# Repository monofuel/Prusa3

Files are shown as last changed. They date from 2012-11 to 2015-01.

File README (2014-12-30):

Modified by monofuel
for monofuel's prusa i3

changes made for 3mm filament and 3/8ths coupling

This is Prusa iteration 3
Published under GPL v3

To start:
Copy configuration.scad.dist to configuration.scad and fill custom
settings section there

RP every .scad in this directory (except complete-printer) once.
Aim for 0.3mm layers and 2.2 extrusion width (width over thickness),
for 0.66mm stroke width. Printer is tested at this setting.

Using doc/complete-printer.scad as a visual clue and doc/manual.txt as a
guide, build the printer.

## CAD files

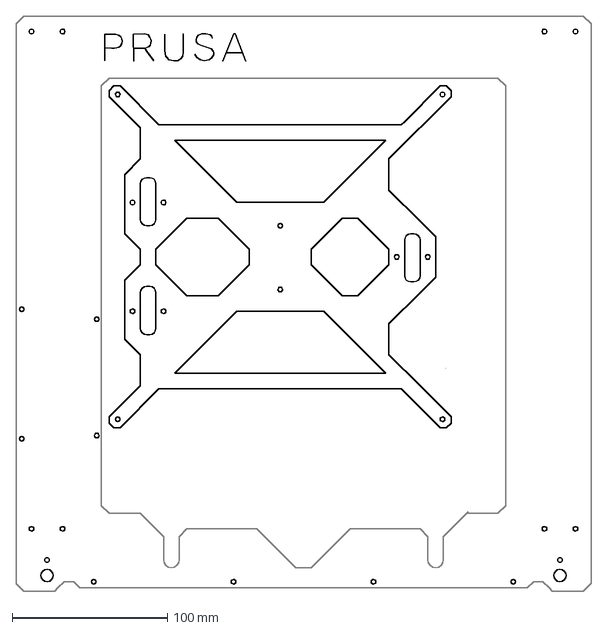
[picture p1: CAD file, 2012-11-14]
src/framev3.dxf
370.0 x 370.0 mm

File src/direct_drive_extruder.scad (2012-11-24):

/*
Designed by indieflow <indieflow@gmail.com>
Direct drive extruder for use with a nema 17 stepper motor and makerbot mk7 drive gear. 
The extruder is designed to use a bowden cable system for 1.75mm filament.
Can be mounted directly on the frame of the new Prusa i3.
The face of the extruder is left open for easy cleaning of the drive gear.
Ajustment of the idler spring tension is achieved by tightening the 4x long m3 screws which are positioned along with the springs and washers at the front of the extruder.
625 bearing on the top of the extruder is for stepper shaft support (not a requirement if no bearings available).
*/

/*
requires:
4x m3 nuts.
8x m3 washers
5x m3x10mm cap screws.
2x m3x14mm cap screws.
4x m3x40mm cap screws.
1x 4mmx12mm round bar or threaded bar. 	//Cut a m4 bolt to size.
1x 4mm OD, 2mm ID pneumatic fitting with m5 thread.
1x mk7 drive gear.
1x 624 bearing.							//idler bearing.
1x 625 bearing.							//used for motor shaft support, can be used without.
4x springs.

Jobs to do:
Assess the fit of the bearing in the idler and main block.
*/

//globals
clearance 	= 0.2;			//adjust if tight or slack once printed.
layer_height	= 0.3;			//used for removable structure.

//uncomment to view.
assembled();				//shows components assembled in position.
//printable();					//places parts in position for exporting as a printable stl.



module printable(){
translate([6,-12,10]) rotate([-90,0,0]) extruder();
translate([26.5,0,0]) rotate([0,0,0]) idler();
translate([20,23,0]) rotate([0,-90,0]) extruder_holder();
//motor bridge supports
translate([0,0,7.25]) cube(([18,2,14.5]),center=true);
translate([0,0,(layer_height/2)+2.2]) cube(([18,25,layer_height]),center=true);
translate([0,0,(layer_height/2)+14.5]) cube(([18,14,layer_height]),center=true);
//idler fixing blanks
translate([35.5,4,2.15]) cylinder(r=2,h=layer_height,center=true,$fn=20);
translate([35.5,-4,2.15]) cylinder(r=2,h=layer_height,center=true,$fn=20);
translate([17.5,-4,2.15]) cylinder(r=2,h=layer_height,center=true,$fn=20);
translate([17.5,4,2.15]) cylinder(r=2,h=layer_height,center=true,$fn=20);
}

module assembled(){
translate([6,-12,57]) rotate([-90,0,0]){
extruder();
translate([13.5,0,12]) rotate([0,-90,0]) idler();
translate([-5.9,33.5,12]) %nema17();
translate([-5.9,2,12]) rotate([90,0,0]) %drive_gear();
translate([-5.9,-8.5,12]) rotate([90,0,0]) %625_bearing();			//drive bearing
translate([7,0,12]) rotate([90,0,0]) %624_bearing();				//idler bearing
translate([0,0,10]) #cylinder(r=0.875,h=60,center=true,$fn=20);	//filament
translate([0,0,35.9]) rotate([0,180,0]) %pneumatic();
}
translate([29,-20,56]) rotate([180,0,0]) rotate([0,0,180]) extruder_holder();
}

module extruder(){
difference(){
union(){
difference(){
//extruder body
translate([-6,-0.5,12]) cube(([18,21,24]),center=true);
//idler bearing cut out
translate([6.5,3,12]) rotate([90,0,0]) cylinder(r=7,h=15,center=true,$fn=30);
//drive gear cleaning access
translate([-15.9,3,12]) cube(([20,15,13.5]),center=true);}
//motor supports
translate([-6,5,26.5]) cube(([30,10,4]),center=true);
translate([-6,-0.5,26.25]) cube(([18,21,4.5]),center=true);
translate([-6,5,-2.5]) cube(([30,10,4]),center=true);
translate([-6,-0.5,-2.25]) cube(([18,21,4.5]),center=true);
translate([3,0,-2.5]) rotate([0,0,45]) cube(([10,5,4]),center=true);
translate([-15,0,-2.5]) rotate([0,0,-45]) cube(([10,5,4]),center=true);
translate([3,0,26.5]) rotate([0,0,45]) cube(([10,5,4]),center=true);
translate([-15,0,26.5]) rotate([0,0,-45]) cube(([10,5,4]),center=true);
translate([5,9,12]) cube(([4,5,30]),center=true);
translate([-17,9,12]) cube(([4,5,30]),center=true);
//motor fixing points
translate([9.6,7.5,27.5]) rotate([90,0,0]) cylinder(r=5,h=5,center=true,$fn=30);
translate([9.6,7.5,-3.5]) rotate([90,0,0]) cylinder(r=5,h=5,center=true,$fn=30);
translate([-21.4,5,27.5]) rotate([90,0,0]) cylinder(r=5,h=10,center=true,$fn=30);
translate([-21.4,5,-3.5]) rotate([90,0,0]) cylinder(r=5,h=10,center=true,$fn=30);
}
union(){
//nema 17 cutout
translate([-5.9,33.5,12]) nema17_cut();
//bracket clearance
translate([8,0,27]) cube(([5,10,6]),center=true);
translate([8,0,-3]) cube(([5,10,6]),center=true);
//motor fixing head clearance
translate([-21.4,-6,-3.5]) rotate([90,0,0]) cylinder(r=2.8,h=20,center=true,$fn=20);
translate([-21.4,-6,27.5]) rotate([90,0,0]) cylinder(r=2.8,h=20,center=true,$fn=20); 
//drive gear cut out
translate([-5.9,3,12]) rotate([90,0,0]) cylinder(r=6.75,h=15,center=true,$fn=30);
//drive shaft cutout
translate([-5.9,0,12]) rotate([90,0,0]) cylinder(r=3,h=22,center=true,$fn=30);
//drive shaft support bearing cutout
translate([-5.9,-8.5,12]) rotate([90,0,0]) cylinder(r=5,h=6,center=true,$fn=30);
translate([-5.9,-9,12]) rotate([90,0,0]) cylinder(r=8+clearance,h=6,center=true,$fn=30);
//idler fixings
translate([-25,4,21]) rotate([90,0,0]) teardrop(r=1.7,h=50,$fn=20);
translate([-25,-4,21]) rotate([90,0,0]) teardrop(r=1.7,h=50,$fn=20);
translate([-25,-4,3]) rotate([90,0,0]) teardrop(r=1.7,h=50,$fn=20);
translate([-25,4,3]) rotate([90,0,0]) teardrop(r=1.7,h=50,$fn=20);
//idler path
translate([11,-2.65,12]) idler_cut();
translate([-23,-2.65,12]) idler_cut();
//filament path
translate([0,0,-20]) rotate([90,0,0]) rotate([0,0,90]) teardrop(r=1.1,h=60,$fn=20);
translate([0,-0.6,9.2]) rotate([45,0,0]) cube(([16,2,2]),center=true);
translate([0,-0.6,14.8]) rotate([45,0,0]) cube(([16,2,2]),center=true);
//pneumatic fitting
translate([0,0,24.25]) rotate([90,0,0]) rotate([0,0,90]) teardrop(r=2.35,h=5,$fn=20);
//fancy top
translate([-6,-17,-0.5]) rotate([45,0,0]) cube(([21,10,50]),center=true);
translate([-5,-17,24.5]) rotate([-45,0,0]) cube(([50,10,50]),center=true);
}
}
}

module idler_block(){
difference(){
minkowski(){
translate([0,0,4.5]) cube(([18.5,9,9]),center=true);
cylinder(r=3,h=1,$fn=30);}
//idler bearing cut out
translate([0,0,6.5]) rotate([90,0,0]) cylinder(r=7.5,h=7,center=true,$fn=30);}
//bearing guides
translate([0,3,6.5]) rotate([90,0,0]) cylinder(r1=4.3,r2=3.3,h=1,center=true,$fn=30);
translate([0,-3,6.5]) rotate([-90,0,0]) cylinder(r1=4.3,r2=3.3,h=1,center=true,$fn=30);
}

module idler_fixings(){
//shaft
translate([0,0,6.5]) rotate([90,0,0]) cylinder(r=2,h=12,center=true,$fn=30);
translate([0,0,9.5]) cube(([4,12,6]),center=true);
//fixings
translate([9,4,24]) cylinder(r=1.7,h=50,center=true,$fn=20);
translate([9,-4,24]) cylinder(r=1.7,h=50,center=true,$fn=20);
translate([-9,-4,24]) cylinder(r=1.7,h=50,center=true,$fn=20);
translate([-9,4,24]) cylinder(r=1.7,h=50,center=true,$fn=20);
//nut traps
translate([9,4,-1]) rotate([0,0,30]) cylinder(r=3.1,h=3,$fn=6);
translate([9,-4,-1]) rotate([0,0,30]) cylinder(r=3.1,h=3,$fn=6);
translate([-9,-4,-1]) rotate([0,0,30]) cylinder(r=3.1,h=3,$fn=6);
translate([-9,4,-1]) rotate([0,0,30]) cylinder(r=3.1,h=3,$fn=6);
}

module idler(){
difference(){
idler_block();
idler_fixings();
}
translate([0,0,6.5]) rotate([90,0,0]) %624_bearing();
translate([0,0,6.5]) rotate([90,0,0]) %cylinder(r=2,h=12,center=true,$fn=30);
}

module idler_cut(){
difference(){
cube(([16,21,25]),center=true);
translate([0,11,14.5]) rotate([-45,0,0]) cube(([20,10,5]),center=true);
translate([0,11,-14.5]) rotate([45,0,0]) cube(([20,10,5]),center=true);}
}

module nema17(){
rotate([-90,0,0]){
translate([0,0,0]) cube([42,42,47],center=true);
//flange
translate ([0,0,-24]) cylinder(r=11,h=3,center=true,$fn=30);
//shaft
translate ([0,0,-36]) cylinder(r=2.5,h=23,center=true,$fn=20);
}
}

module nema17_cut(){
rotate([-90,0,0]){
translate([0,0,0]) cube([42+(clearance*2),42+(clearance*2),47],center=true);
//flange
translate ([0,0,-24-(clearance/2)]) cylinder(r=11+clearance,h=3+clearance,center=true,$fn=30);
//shaft
translate ([0,0,-36-(clearance/2)]) cylinder(r=2.5+clearance,h=23+clearance,center=true,$fn=20);
//fixings
translate([15.5,15.5,-36]) cylinder(r=1.7,h=30,center=true,$fn=20);
translate([15.5,-15.5,-36]) cylinder(r=1.7,h=30,center=true,$fn=20);
translate([-15.5,-15.5,-36]) cylinder(r=1.7,h=30,center=true,$fn=20);
translate([-15.5,15.5,-36]) cylinder(r=1.7,h=30,center=true,$fn=20);
}
}

module gear(){
difference(){
union(){
cylinder(r=6.3,h=11,center=true,$fn=30);
}
union(){
translate([0,0,0]) cylinder(r=2.6,h=13,center=true,$fn=30);
translate([0,4,-2.5]) rotate([90,0,0]) cylinder(r=1.5,h=6,center=true,$fn=30);
translate([0,0,2]) rotate_extrude(convexity=10,$fn=100)
translate([7.3,0,0])
circle(r=2,$fn=100);
}
}
}


module bearing_slot(){
difference(){ 
cylinder(r=6.5,h=4.25,center=true,$fn=30);
cylinder(r=5.9,h=5.25,center=true,$fn=30);
}
}

module drive_gear(){
difference(){
gear();
translate([0,0,2]) bearing_slot();
}
}

module 624_bearing(){
difference(){
cylinder(r=6.5,h=5,center=true,$fn=30);
cylinder(r=2,h=6,center=true,$fn=30);
}
}

module 625_bearing(){
difference(){
cylinder(r=8,h=5,center=true,$fn=30);
cylinder(r=2.5,h=6,center=true,$fn=30);
}
}
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

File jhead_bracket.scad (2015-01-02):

/*
Designed by indieflow <indieflow@gmail.com>
This file contains a J-head attachment for use with the new Prusa i3 X-carriage.
My aim was to design a part that was:-
Minimal as possible to reduce the weight on the X-axis, as such reducing noise and strain.
Lock the J-head in tight against the carriage helping to reduce vibration in the hotend.
To incorporate a cooling system for the j-head peek with out blowing on the print (for ABS).
Allow the use of a bowden cable and direct drive via a Nema 17 stepper motor.
*/

/*
requires:
1x j-head mkV 1.75mm filament with 0.5/0.35 nozzle.
1x 4mm OD, 2mm ID pneumatic fitting with m5 thread.
PTFE tube to match fitting.							
25mm 12V DC fan.
2x m3 nuts.
2x m3 washers.
2x m3x 40mm cap screws.
6x self taping screws
2x cable ties
*/

use<x-carriage.scad>

//globals
clearance = 0.2;			//adjust if tight or slack once printed.

//uncomment to view.
//assembly();			//shows components assembled in position.
print();					//places parts in position for exporting as a printable stl.



module clamp(){
difference(){
union(){
translate([0,-0.25,0]) cube(([24,5.5,9]),center=true);
}
union(){
translate([0,8,0]) jhead_cut();
//fixings
//monofuel - increased cylender sizes so that
//screws can slide freely without threading. this piece
//just holds the j-head, and the screws should thread into the main part.
//i also increased the holds to sink the screw heads in easier.
translate([9,0,0]) rotate([90,0,0]) cylinder(r=1.6,h=20,center=true,$fn=20);
translate([-9,0,0]) rotate([90,0,0]) cylinder(r=1.6,h=20,center=true,$fn=20);
translate([9,-6,0]) rotate([90,0,0]) cylinder(r=2.8,h=10,center=true,$fn=20);
translate([-9,-6,0]) rotate([90,0,0]) cylinder(r=2.8,h=10,center=true,$fn=20);
}
}
}

module blank(){
difference(){
union(){
cube(([18,12,1]),center=true);
translate([0,0,-1.25]) cube(([16,12,1.5]),center=true);
}
union(){
translate([0,6,0]) jhead_cut();
}
}
}

module peek_guard(){
difference(){
union(){
//fixing supports
translate([-12,12,0]) rotate([90,0,0]) cylinder(r=4.5,h=24,center=true,$fn=30);
translate([12,12,0]) rotate([90,0,0]) cylinder(r=4.5,h=24,center=true,$fn=30);
difference(){
translate([0,12,0]) cube(([24,24,9]),center=true);
translate([0,31.1,0]) rotate([45,0,0]) cube(([30,10,42]),center=true);}
difference(){
//body
translate([0,12,-18]) cube(([33,24,36]),center=true);
//slanted back
translate([17,26.7,-16]) rotate([0,0,-45]) cube(([30,10,42]),center=true);
translate([-17,26.7,-16]) rotate([0,0,45]) cube(([30,10,42]),center=true);}
}
union(){
//lower corners
translate([16.5,12,-37.6]) rotate([0,-45,0]) cube(([30,26,10]),center=true);
translate([-16.5,12,-37.6]) rotate([0,45,0]) cube(([30,26,10]),center=true);
//fixing holes
//monofuel
//increased hole sizes to allow for easier threading
translate([12,10,0]) rotate([90,0,0]) cylinder(r=1.5,h=60,center=true,$fn=30);
translate([-12,10,0]) rotate([90,0,0]) cylinder(r=1.5,h=60,center=true,$fn=30);
//pneumatic fitting
//monofuel
//increased pneumatic fitting hole to make threading easier, and allow
//the coupling to thread in all the way. i measured the thread on my coupling
//at 8mm. Perhaps the whole part should be scaled up an extra 1mm to get full 8mm?
//set to 7mm atm. close nuff.
translate([0,12,-2]) rotate([90,0,0]) rotate([0,0,90]) teardrop(r=4.8,h=7,$fn=40);
//nut for pneumatic fitting
//monofuel - removing this, because i like threading plastic.
//translate([0,12,-1]) rotate([0,0,30]) cylinder(h=4,r=4.6,$fn=6);
//translate([0,0,1]) cube(([8,24,4]),center=true);
//jhead
translate([0,12,-28]) rotate([0,0,90]) jhead_cut();
translate([0,0,-6.1]) cube(([16+(clearance*2),24,4.75]),center=true);
translate([0,0,-10]) cube(([12.1+(clearance*2),24,7.5]),center=true);
translate([0,0,-28]) cube(([16+(clearance*2),24,30]),center=true);
//side vents
translate([0,12,-23.75]) cube(([25.5,8,13.5]),center=true);
translate([18,12,-23.75]) vent();
translate([-18,12,-23.75]) rotate([0,0,180]) vent();
//fan fixing hole
//monofuel
//increased hole size to play nicely with threading and m3 screws.
//caveat: i don't actually have a fan to use atm, so i don't know
//what screws to use. i'm assuming m3.
//i also shrunk the holes to 8mm depth, assuming that i'm using
//10mm long screws to attach the fan, it should be fine.
translate([0,29,-23.35]) rotate([90,0,0]){
translate([10.15,10.15,10]) cylinder(r=1.5,h=8,center=true,$fn=20);
translate([10.15,-10.15,10]) cylinder(r=1.5,h=8,center=true,$fn=20);
translate([-10.15,-10.15,10]) cylinder(r=1.5,h=8,center=true,$fn=20);
translate([-10.15,10.15,10]) cylinder(r=1.5,h=8,center=true,$fn=20);}
//fan vent
translate([0,20.6,-23.35]) rotate([90,0,0]) cylinder(r1=11.8,r2=5,h=7.2,center=true,$fn=50);    //r2=6 for 40 degree,  r2=5 for 45ish!
//slotted peek section clearance
translate([0,12,-23.75]) cylinder(r=10,h=16.5,center=true,$fn=50);
translate([0,0,-23.75]) cube(([20,24,16.5]),center=true);
//filament
//monofuel
//increased to 1.6 for 3mm filament with some leeway.
// later increased to 1.7 as 1.6 was a bit tight.
translate([0,12,0]) cylinder(r=1.7,h=60,center=true,$fn=20);
//bottom blank
translate([0,6,-34]) cube(([18+(clearance*2),12+(clearance*2),1+(clearance*2)]),center=true);
//clamp
translate([0,2,-10.75]) cube(([24+(clearance*2),11,9+(clearance*2)]),center=true);
translate([0,2,-15]) cube(([20,11,3]),center=true);
//jhead clamp fixings
//monofuel
//increased hole size to make it easier to thread
//decreased depth since we're only using 10mm 3m cap screws
translate([9,7.5,-10.75]) rotate([90,0,0]) cylinder(r=1.5,h=15,center=true,$fn=20);
translate([-9,7.5,-10.75]) rotate([90,0,0]) cylinder(r=1.5,h=15,center=true,$fn=20);
//cableties
translate([16.5,24.25,-8.75]) cabletie();
translate([-16.5,24.25,-8.75]) cabletie();
//translate([0,0,17]) cube(([50,50,50]),center=true);
}
}
}

module jhead(){
//peek
cylinder(r=8,h=30,center=true,$fn=30);
translate([0,0,15+2.25]) cylinder(r=6.05,h=5.5,center=true,$fn=30);
translate([0,0,15+4.5+2.375]) cylinder(r=8,h=4.75,center=true,$fn=30);
//nozzle
translate([3.75,0,-15-4.125]) cube(([12.75,12.75,8.25]),center=true);
}

module jhead_cut(){
//peek
cylinder(r=8+clearance,h=30,center=true,$fn=50);
translate([0,0,15+2.25]) cylinder(r=6.05+clearance,h=5.5,center=true,$fn=50);
translate([0,0,15+4.5+2.375]) cylinder(r=8+clearance,h=4.75+clearance,center=true,$fn=50);	//top clearance equal 0.1 either side at mo, may need adjusting!!!
//nozzle
translate([3.75,0,-15-4.125]) cube(([12.75,12.75,8.25]),center=true);
}

module fan(){
difference(){
union(){
//body
cube(([25.3,25.3,10]),center=true);
}
union(){
//fan
cylinder(r=11.8,h=12,center=true,$fn=30);
//fixings
translate([10.15,10.15,0]) cylinder(r=1.5,h=12,center=true,$fn=20);
translate([10.15,-10.15,0]) cylinder(r=1.5,h=12,center=true,$fn=20);
translate([-10.15,-10.15,0]) cylinder(r=1.5,h=12,center=true,$fn=20);
translate([-10.15,10.15,0]) cylinder(r=1.5,h=12,center=true,$fn=20);
}
}
}

module vent(){
difference(){
union(){
translate([-3,0,0]) rotate([0,0,0]) cube(([5,18,24]),center=true);
}
union(){
translate([0,12.8,0]) rotate([0,0,45]) cube(([20,5,40]),center=true);
translate([0,-12.8,0]) rotate([0,0,-45]) cube(([20,5,40]),center=true);
translate([0,0,-5]) rotate([0,-45,0]) cube(([30,40,5]),center=true);
translate([0,0,15.5]) rotate([0,-45,0]) cube(([30,40,5]),center=true);
translate([-7.8,0,0]) rotate([0,0,0]) cube(([5,10,15]),center=true);
}
}
}

module cabletie(){
difference(){
cylinder(h=3,r=8);
translate([0,0,-0.5]) cylinder(h=4,r=6);
}
}

module pneumatic(){
difference(){
union(){
cylinder(r=4.5,h=14.5,center=true,$fn=30);
translate([0,0,4]) cylinder(r=2.5,h=14.5,center=true,$fn=30);
}
union(){
translate([0,0,-5]) cylinder(r=2,h=14.5,center=true,$fn=20);
translate([0,0,5]) cylinder(r=1,h=14.5,center=true,$fn=20);
}
}
}

module assembly(){
rotate([0,0,180]){
translate([-16.5,0,-24]) rotate([90,0,180]) %x_carriage();}
translate([0,12 ,12]) rotate([180,0,0]) %pneumatic();
peek_guard();
translate([0,12,-28]) rotate([0,0,90]) %jhead();
translate([0,29,-23.35]) rotate([90,0,0]) %fan();
translate([0,6,-34]) blank();
translate([0,4,-10.75]) clamp();
}

module print(){
translate([0,15.75,24]) rotate([-90,0,0]) peek_guard();
translate([0,26,4.5]) clamp();
translate([0,-29,0.5]) rotate([180,0,0]) blank();
}

module teardrop (r=8,h=20)
{
rotate([-270,0,90])
linear_extrude(height=h)
{
circle(r=r);
polygon(points=[[0,0],[r*cos(30),r*sin(30)],[0.5*r,r],[-0.5*r,r],[-r*cos(30),r*sin(30)]],
paths=[[0,1,2,3,4]]);
}
}

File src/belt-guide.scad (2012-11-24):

// PRUSA iteration3
// 624 bearing belt guide
// GNU GPL v3
// Josef Průša <iam@josefprusa.cz> and contributors
// http://www.reprap.org/wiki/Prusa_Mendel
// http://prusamendel.org

wall= 1.2;
clearence= 0.1; 

module belt_guide_base(){
 cylinder(r=6.5+wall+clearence, h=4.5, $fn=50);
 cylinder(r=6.5+wall+clearence+2*wall, h=0.8, $fn=50);
}

module belt_guide_holes(){
 translate([0,0,1.8]) cylinder(r=6.5+clearence, h=10, $fn=50);
 translate([0,0,-1]) cylinder(r=6.5+wall+clearence-2*wall, h=10, $fn=50);
}

// Final part
module belt_guide(){
 difference(){
  belt_guide_base();
  belt_guide_holes();
 }
}

belt_guide();

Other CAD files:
src/jhead_bracket.scad
src/x-carriage.scad
src/y-belt-holder.scad
src/y-corners.scad
src/y-idler.scad
src/z-axis-bottom.scad
src/z-axis-top.scad

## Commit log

2012-11-14 T2.5 belt fit
    Altered tooth profile to fit T2.5 belts and centred excess belt cut out.
    [x-carriage.scad]
2012-11-14 Removed old frame
    [frame.dxf, framev3.dxf]
2012-11-14 T2.5 belt fit
    Altered tooth profile to fit T2.5 belts
    [y-belt-holder.scad]
2012-11-20 Improved print quality
    Changed vertical through holes to teardrop shape for better print
    quality.
    [y-corners.scad]
2012-11-20 Improved print quality
    Changed vertical through hole to teardrop shape for better print
    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
    [y-idler.scad]
2012-11-21 J-head bracket
    New design for a bowden system that I'm trying on the i3.
    [jhead_bracket.scad]
2012-11-21 Direct Drive Extruder
    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
    [direct_drive_extruder.scad]
2012-11-21 Removed files
    As I'm not using the standard extruder for my i3, these designs are no
    longer needed.
    [compact-extruder.scad, fan-mount.scad]
2012-11-21 Repositioned idler
    Realised that idler was positioned wrong for printing.
    [direct_drive_extruder.scad]
2012-11-22 Bearing adjustment
    624 bearing dimensions and positioning altered, also included 625
    bearing for stepper shaft support.
    [direct_drive_extruder.scad]
2012-11-24 Adjusted fixture lists
    [direct_drive_extruder.scad, jhead_bracket.scad]
2012-11-24 Adjusted bearing cutout depth
    Adjusted depth as bearing was too loose when printing at 0.2mm layer
    height.
    [belt-guide.scad]
2012-12-08 Incoporated Josefs Updates
    Increased long Y-axis threaded rod to M10 for greater frame support.
    Also intergrated washer indent.
    [y-corners.scad]
2012-12-08 Incoporated Josefs Updates
    Support bar added.
    [z-axis-top.scad]
2012-12-08 Incoporated Josefs Updates
    Added support bar.
    [z-axis-bottom.scad]
2012-12-13 Altered BOM
    Changed the main y-carriage support bars to M10.
2015-01-02 general printing improvements
    [jhead_bracket.scad]
